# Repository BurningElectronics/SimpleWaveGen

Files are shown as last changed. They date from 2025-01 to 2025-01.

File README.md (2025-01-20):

# SimpleWaveGen
A simple waveform generator using Arduino nano and a few more components

The components used are:

1. Arduino nano
2. SSD1306 32x128 OLED display
3. AD9833 waveform generator module
4. 2x Screw terminal (2P 5.0mm)
5. RL207 diode, you can use anyone you want, as long as it fits
6. SS12F44G4 Switch
7. 50V 100uF Capacitor (D8.0mm, P3.50mm), symbolic value
8. 3x 2-Pin Pushbuttons
9. Some female headers
10. 8x 10k 1/4W resistors, you can use any reasonable value for pull-up/down purposes

<br/>
<br/>
<br/>

How does it work?

The arduino nano sends the waveform type and frequency via SPI to the AD9833, that generates the requested waveform.

While doing this, the OLED display (SSD1306) is updated by the arduino via I2C, with dsplayed frequency, waveform type and digit position.

To set the frequency an encoder it's used.

To navigate between digits two pushbuttons, LEFT (<-) and RIGHT (->), are used.

To change Waveform type a third pushbutton (MODE) it's used.

To reset the digit press the encoder button.

Want this PCB manufactured?
Check www.pcbway.com
You can directly upload the file in the gerber folder and customize as you wish!

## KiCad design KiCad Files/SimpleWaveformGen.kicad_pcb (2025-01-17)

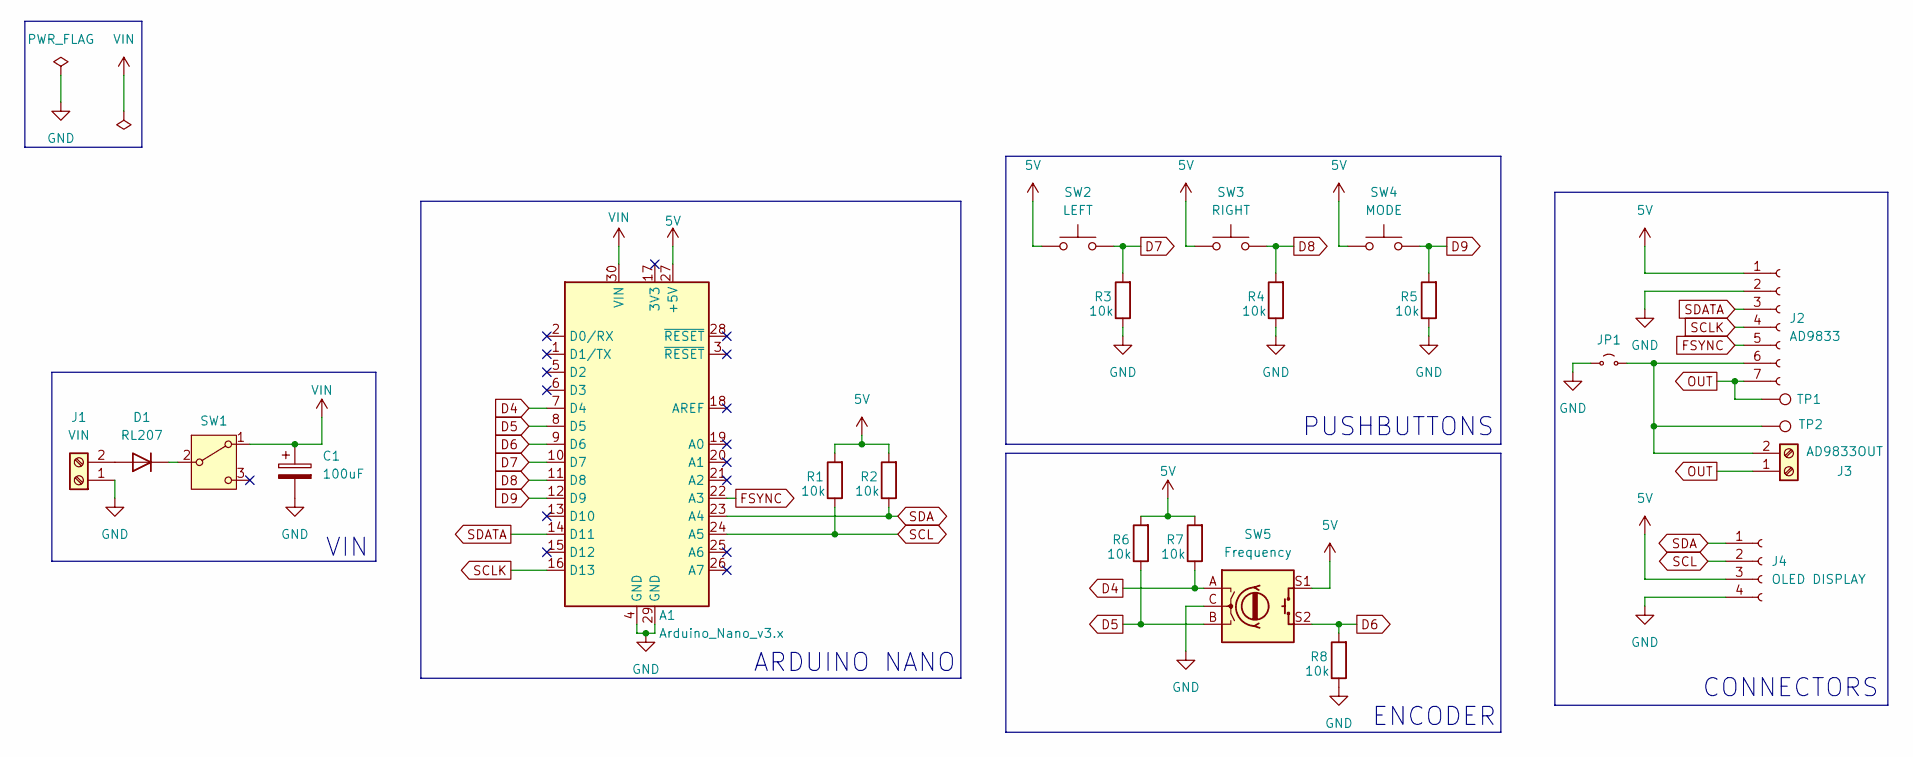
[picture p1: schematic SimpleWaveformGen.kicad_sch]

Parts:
A1: Arduino_Nano_v3.x; Arduino_Nano
C1: 100uF; CP_Radial_D8.0mm_P3.50mm
D1: RL207; D_DO-15_P12.70mm_Horizontal
J1: VIN; ScrewTerminal-2P
J2: AD9833; PinSocket_1x07_P2.54mm_Vertical
J3: AD9833OUT; ScrewTerminal-2P
J4: OLED DISPLAY; PinSocket_1x04_P2.54mm_Vertical
JP1: Jumper_2_Small_Open; SolderJumper-2_P1.3mm_Open_RoundedPad1.0x1.5mm
R1, R2, R3, R4, R5, R6, R7, R8: 10k; R_Axial_DIN0207_L6.3mm_D2.5mm_P10.16mm_Horizontal
SW1: SW_SPDT; Switxh SPDT - SS12F44G4
SW2: LEFT; Pushbutton - DIP-2
SW3: RIGHT; Pushbutton - DIP-2
SW4: MODE; Pushbutton - DIP-2
SW5: Frequency; RotaryEncoder_Alps_EC11E-Switch_Vertical_H20mm
TP1, TP2: TestPoint; PinHeader_1x01_P2.54mm_Vertical

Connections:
5V: A1.27 (+5V), J2.1, J4.3, R1.2, R2.2, R6.2, R7.2, SW2.1, SW3.1, SW4.1, SW5.S1
D4: A1.7 (D4), R7.1, SW5.A
D5: A1.8 (D5), R6.1, SW5.B
D6: A1.9 (D6), R8.2, SW5.S2
D7: A1.10 (D7), R3.2, SW2.2
D8: A1.11 (D8), R4.2, SW3.2
D9: A1.12 (D9), R5.2, SW4.2
FSYNC: A1.22 (A3), J2.5
GND: A1.4 (GND), A1.29 (GND), C1.2, J1.1, J2.2, J4.4, JP1.1 (A), R3.1, R4.1, R5.1, R8.1, SW5.C
unnamed: D1.2 (A), J1.2
unnamed: D1.1 (K), SW1.2 (B)
unnamed: J2.6, J3.2, JP1.2 (B), TP2.1
OUT: J2.7, J3.1, TP1.1
SCL: A1.24 (A5), J4.2, R1.1
SCLK: A1.16 (D13), J2.4
SDA: A1.23 (A4), J4.1, R2.1
SDATA: A1.14 (D11), J2.3
VIN: A1.30 (VIN), C1.1, SW1.1 (A)

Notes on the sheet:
CONNECTORS
VIN
ENCODER
ARDUINO NANO
PUSHBUTTONS

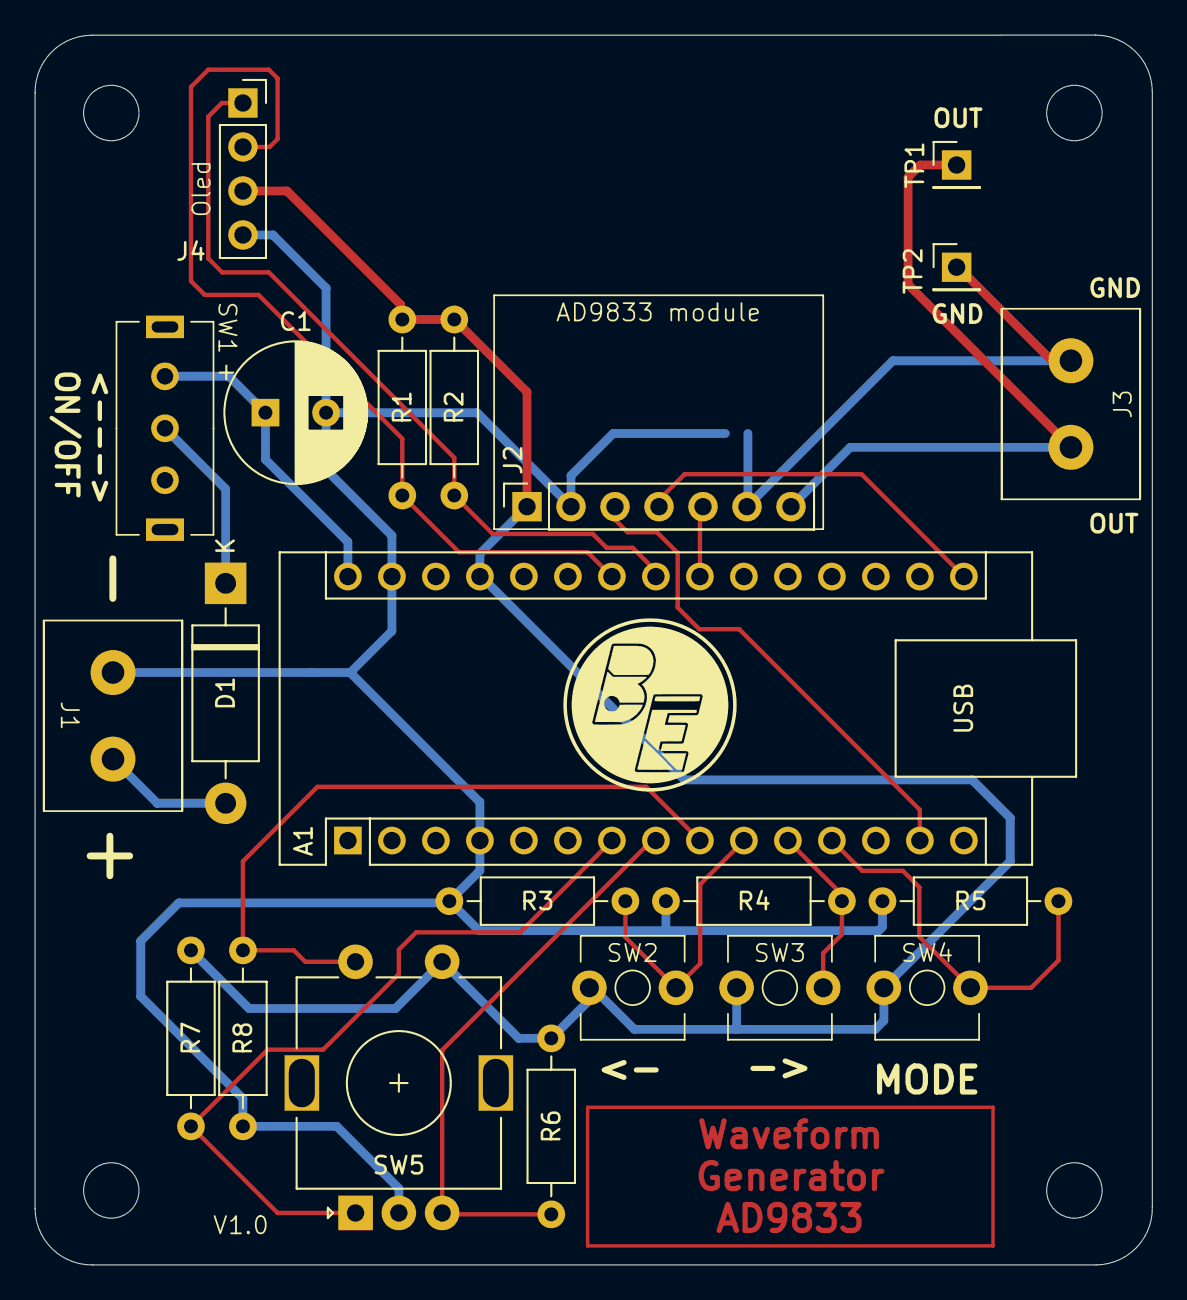
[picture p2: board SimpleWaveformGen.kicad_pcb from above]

Board: 2 copper layers, 64.5 x 71.0 mm, 23 parts (1 on the bottom side), 18 nets.

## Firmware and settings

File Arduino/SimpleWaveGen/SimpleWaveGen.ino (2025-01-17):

#include <AD9833.h>     // Include AD9833 library (LINK: https://github.com/Billwilliams1952/AD9833-Library-Arduino/tree/master)

#include <EasyButton.h> // Include EasyButton library (LINK: https://github.com/Billwilliams1952/AD9833-Library-Arduino/tree/master)

#include <Wire.h> // Include I2C library

#include <Adafruit_SSD1306.h> // Include SSD1306 library (LINK: https://github.com/adafruit/Adafruit_SSD1306)

#define FNC_PIN A3       // Can be any digital IO pin, used for AD9833

#define SCREEN_ADDRESS 0x3C // Address: 0x3D for 128x64, 0x3C for 128x32

Adafruit_SSD1306 display(128, 32, &Wire, -1); // Initialize Screen: X size, Y size, I2C, reset (see Adafruit library) 

const byte pinA = 4, pinB = 5, encoderBPin = 6, leftBPin = 7, rightBPin = 8, modeBPin = 9; //Encoder pin a and b, and pins of the various buttons

bool aVal = 0, aLast = 0, update = 0; //aVal and aLast used for rotary encoder reading, update used for waveform update
byte mode = 0, pos = 0; //mode used for the types of waveforms, pos is the position of the digit we are working on

int encoder = 0; //encoder variable

byte digit[] = {0, 0, 0, 1, 0, 0}; //digits stored on array
String stringMode[] = {"Square", "Triangular", "Sine"}; //Arrsy used to print waveform type on SSD1306 based on mode

unsigned long freq = 1000; //frequency

EasyButton encoderButton(encoderBPin); //Initialize the various buttons connected to respective pins
EasyButton leftButton(leftBPin);
EasyButton rightButton(rightBPin);
EasyButton modeButton(modeBPin);

AD9833 gen(FNC_PIN); //Initialize AD9833

void setup() {

  Wire.begin(); //I2C begin

  if(!display.begin(SSD1306_SWITCHCAPVCC, SCREEN_ADDRESS)) { //If display is not connected loop forever
    for(;;); 
  }

  display.clearDisplay(); //Clear display
  display.setTextColor(SSD1306_WHITE); // Draw white text
  display.setTextSize(2); //Text size

  pinMode(4, INPUT); //Encoder pin a and b as INPUT so we can read when it's rotating
  pinMode(5, INPUT);

  aLast = digitalRead(pinA); //Assign latest value to aLast

  encoderButton.onPressed(digitResest); //When one of the button is pressed do respective function (see various functions below)
  leftButton.onPressed(left);
  rightButton.onPressed(right);
  modeButton.onPressed(modeChange);


  gen.Begin(); //Used to enable 
  gen.EnableOutput(true);   // Turn on output

  updateDisplay(); //Update display so we can see the writing on the display at the beginning
  gen.ApplySignal(SQUARE_WAVE, REG0, freq); //output signal at the beginning so we can see if it's all OK. 1kHz square wave as standard

}

void loop() {

  if(update) { //Any time we need to update the waveform we need to:

    freq = digit[0] + digit[1] * 10UL + digit[2] * 100UL + digit[3] * 1000UL + digit[4] * 10000UL + digit[5] * 100000UL; //Set the frequency
    
    if(mode == 0)       gen.ApplySignal(SQUARE_WAVE, REG0, freq); //Apply waveform type based on mode
    else if(mode == 1)  gen.ApplySignal(TRIANGLE_WAVE, REG0, freq);
    else                gen.ApplySignal(SINE_WAVE, REG0, freq);

    update = 0; //No more need to update

  }

  
  encoderButton.read(); //Read all the 4 buttons
  leftButton.read();
  rightButton.read();
  modeButton.read();

  readEncoder(); //Read any change in encoder position

}

void modeChange() { //Mode change function

  if(mode < 2) mode++; //We have 3 modes, Square, Triangle, Sine. So we increase only up to 2 (0, 1, 2)
  else mode = 0; //If mode is 2, we return to 0 instead of increasing mode

  updateDisplay(); //Every time mode is changed we need to update the display

  update = 1; //Every time mode is changed we need to update waveform output on AD9833

}

void left() { //Change position to the left function

  if(pos < 5) pos++; //If the position is less than 5 we can go to the left (0, 1, 2, 3, 4, 5)
  else pos = 0; //If the position is 5, we cannot go further to the left so we return to the 0 (first) digit

  encoder = digit[pos] * 2; //Each time we change position, the encoder position needs to be matched to the digit

  updateDisplay(); //Every time we change position we need to update position counter

}

void right() { //Change position to the right function

  if(pos > 0 && pos <= 5) pos--; //If the position is greater than 0 we can go to the right (5, 4, 3, 2, 1, 0)
  else pos = 5; //If position is less than 0 we cannot go further to the right so we return to the 5 (last) digit

  encoder = digit[pos] * 2; //Each time we change position, the encoder position needs to be matched to the digit

  updateDisplay(); //Every time we change position we need to update position counter

}

void digitResest() { //Digit reset function

  digit[pos] = 0; //Reset the digit at the correct position

  updateDisplay(); //Every time we reset the digit we need to update frequency

  update = 1; //Every time we reset the digit we need to update frequency output

}

void readEncoder() { //Encoder read function
 
 aVal = digitalRead(pinA); //Assign the value based on the readings
 
 if (aVal != aLast){  //If we fid that the value has changed then:

  if (digitalRead(pinB) != aVal) encoder--; //If we rotate counterclockwise we lower encoder counter
  else encoder++; //If we rotate clockwise we increase counter

  if(encoder > 19) encoder = 0; //If we rotate clocwise too much clockwise we don't want our dugit to go over encoder/2 or 19 (truncated by conversion), so we start back to 0
  else if(encoder < 0) encoder = 19; //If we rotate too much counterclockwise we don't want our digit to go under 0, so we start back to 19

  encoder = constrain(encoder, 0, 19); //Constrain encoder for better results

  digit[pos] = encoder / 2; //The digit needs to be encoder / 2 or from 0 to 9

  updateDisplay(); //Every time we change digit value frequency needs to be updated

  update = 1; //Every time we change digit value we need to update frequency output

 }
 
 aLast = aVal; //aLast now it's aVal so that we can see changes next time

}


void updateDisplay() { //Update display function

  display.clearDisplay(); //We clear all the display
  display.setCursor(0, 0); //Set the cursor to top-left corner
  for(int i = 0; i < 6; i++) display.print(digit[5-i]); //Display digits from the greatest to the lowest from left to right
  display.print(" P:"); //Print the position
  display.print(pos);
  display.setCursor(0, 16); //Set cursor to match "the second line"
  display.print(stringMode[mode]); //Print the waveform type based on the mode
  display.display(); //Save and update changes to display

}

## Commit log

2025-01-17 KiCad Files
    [SimpleWaveformGen.kicad_pcb, SimpleWaveformGen.kicad_sch]
2025-01-17 Custom Footprint for Switch
2025-01-17 Custom footprint for Screw Terminal
2025-01-17 Arduino file
2025-01-17 Gerbers for PCBWay
